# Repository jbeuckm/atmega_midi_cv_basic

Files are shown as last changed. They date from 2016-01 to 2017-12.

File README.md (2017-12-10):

# atmega_midi_cv_basic
Simple gate+pitch+velocity with one 4822

Portamento time is controlled by MIDI CC #5.

When more than one MIDI note is active, the frequency CV is set according to the value of MIDI CC #80 as follows:

CC #80 | Note Priority
--- | ---   
0-31 | Lowest Note
32-63 | Highest Note
64-127 | Highest Velocity (default)

The MIDI channel can be set by sending the following SYSEX message: 
`0x77 0x16 0x01 0x00 0xcc` where cc is the new channel.

Parts placement for Release v0.5:

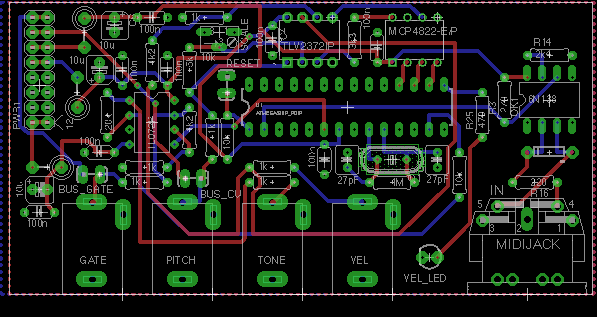
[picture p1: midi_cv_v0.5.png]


For 6N137 instead of 6N138, build with these changes:

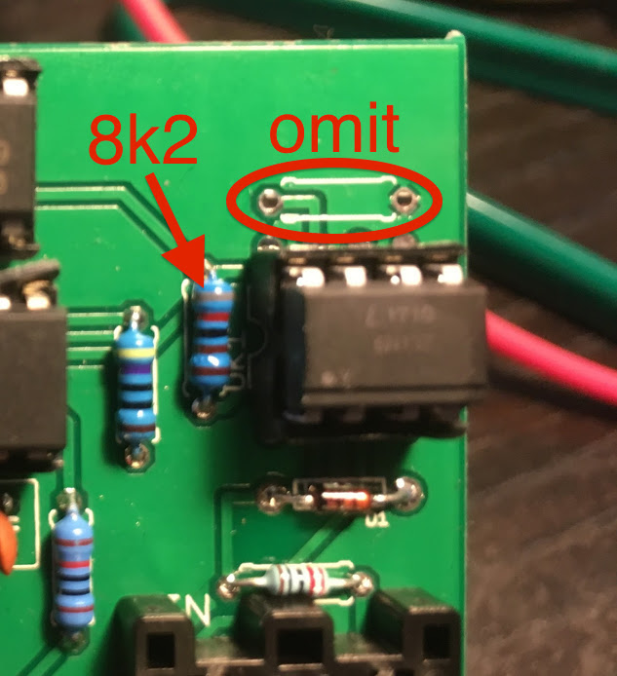
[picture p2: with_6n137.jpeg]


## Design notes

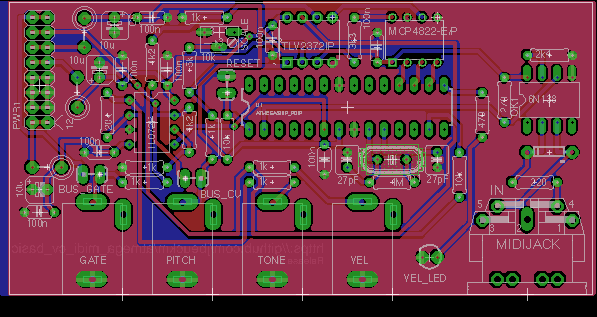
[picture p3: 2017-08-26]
eagle/midi_cv_basic.png

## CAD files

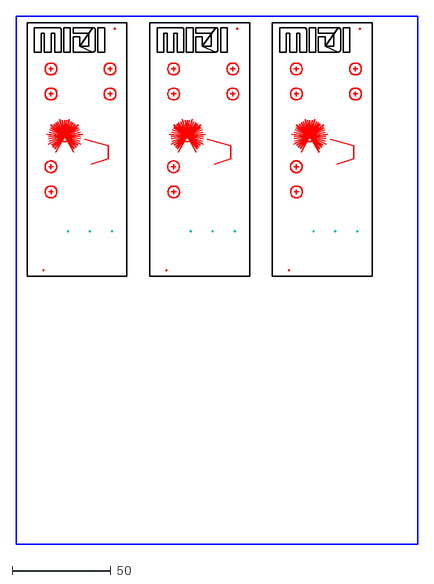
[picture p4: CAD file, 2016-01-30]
panel/basic_midi_cv_panel.dxf
203.2 x 267.2

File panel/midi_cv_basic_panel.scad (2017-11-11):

translate([0,0,2]) rotate([180]) EuroPanel("MIDI", 7);

module EuroPanel(label, hp=8) {
    
  font = ".SF Compact Display:style=Bold";
  labelFontSize = 5.8;

  sideOffset = 5;
  panelWidth = hp*5.08;

  translate([panelWidth,0,0]) scale([-1,1,1]) Support();
  
  
  difference() {
    cube([hp*5.08, 128.5, 2]);
      
    translate([1,118,1])  {
        linear_extrude(height=2, convexity=4) text(label, size=8, font=font);
    }
    translate([7.5,3]) MountingHole();
    translate([panelWidth - 7.5, 128.5 - 3]) MountingHole();

    translate ([sideOffset, 117, 0]) union() {
        translate([0,-87.750,0]) MIDIHole();
        translate([0,-71.39,0]) LEDHole();
        translate([0,-59.97,0]) JackHole();
        translate([0,-44.7,0]) JackHole();
        translate([0,-29.43,0]) JackHole();
        translate([0,-14.17,0]) JackHole();
    }
    translate([18,10,1]) {
      translate([0,90])   {
          linear_extrude(height=2, convexity=4) text("gate", size=labelFontSize, font=font);
      }
      translate([0,75])   {
          linear_extrude(height=2, convexity=4) text("pch", size=labelFontSize, font=font);
      }
      translate([0,60])   {
          linear_extrude(height=2, convexity=4) text("tone", size=labelFontSize, font=font);
      }
      translate([0,45])   {
          linear_extrude(height=2, convexity=4) text("velo", size=labelFontSize, font=font);
      }
  }

  }
/*
    color("green", .3)
        translate([panelWidth - sideOffset, 14.25,2])
            cube([1,100,50]);
            */
}

module KnobHole() { translate([12.5,0,-.5]) cylinder(h=3, d=8, $fn=12); }

module JackHole() { translate([6,0,-.5]) cylinder(h=3, d=6.5, $fn=12); }

module LEDHole() { translate([10,0,-.5]) cylinder(h=3, d=5.3, $fn=12); }

module MIDIHole() { translate([10.5,0,-.5]) cylinder(h=3, d=18.5, $fn=24); }

module Support() {
    translate([0,10,0])
    rotate([-90,0,0])
  linear_extrude(108.5)
    polygon([[0,0], [0,2], [1.5,5], [3,5], [3,0]]);
}


module MountingHole() {
  hull() {
    translate([-2,0,-.5]) cylinder(h=3, r=1.6, $fn=12);
    translate([2,0,-.5]) cylinder(h=3, r=1.6, $fn=12);
  }
}

echo(version=version());

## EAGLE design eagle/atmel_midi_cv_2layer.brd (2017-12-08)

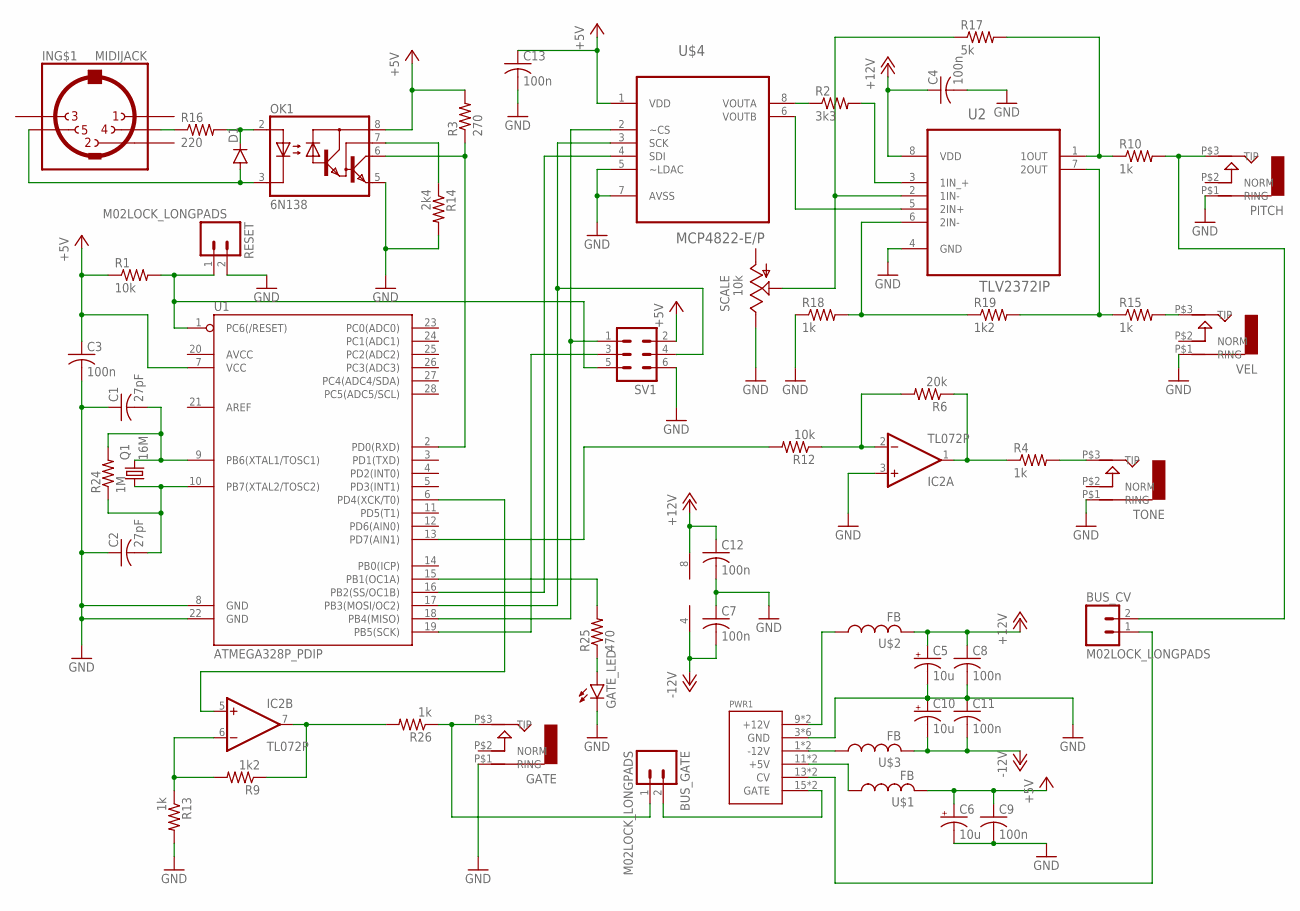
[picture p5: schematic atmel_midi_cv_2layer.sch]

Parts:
BUS_CV: M02LOCK_LONGPADS; 1X02_LOCK_LONGPADS
BUS_GATE: M02LOCK_LONGPADS; 1X02_LOCK_LONGPADS
C1, C2: 27pF; C025-040X050
C3, C4, C7, C8, C9, C11, C12, C13: 100n; C050-024X044
C5, C6, C10: 10u; B45181A
D1: DIODE1N4148; DIODE-1N4148
GATE: AUDIO-JACKITEAD; JACK-90DEG-ITEAD
GATE_LED: LED3MM
IC2: TL072P; DIL08
IN: MIDIJACK; CP-2350
OK1: 6N138; DIL08
PITCH: AUDIO-JACKITEAD; JACK-90DEG-ITEAD
PWR1: POWER; POWER_16
Q1: 16M; HC49/S
R1, R12: 10k; 0207/7
R2: 3k3; 0207/7
R3: 270; 0207/7
R4, R10, R13, R15, R18, R26: 1k; 0207/7
R6: 20k; 0207/7
R9, R19: 1k2; 0207/7
R14: 2k4; 0207/7
R16: 220; 0207/7
R17: 5k; 0207/7
R24: 1M; 0207/7
R25: 470; 0207/7
RESET: M02LOCK_LONGPADS; 1X02_LOCK_LONGPADS
SCALE: 10k; B64W
SV1: MA03-2
TONE: AUDIO-JACKITEAD; JACK-90DEG-ITEAD
U1: ATMEGA328P_PDIP; DIL28-3
U2: TLV2372IP; DIP254P762X508-8
U$1, U$2, U$3: FB
U$4: MCP4822-E/P; DIP254P762X432-8
VEL: AUDIO-JACKITEAD; JACK-90DEG-ITEAD

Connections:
+5V: C3.1, C6.+, C9.1, C13.1, OK1.8 (VCC), R1.1, R3.2, SV1.2, U1.7 (VCC), U$1.P$2 (2), U$4.1 (VDD)
+12V: C4.1, C5.+, C8.1, C12.1, IC2.8 (V+), U2.8 (VDD), U$2.P$2 (2)
-12V: C7.2, C10.-, C11.2, IC2.4 (V-), U$3.P$2 (2)
GND: C1.1, C2.1, C3.2, C4.2, C5.-, C6.-, C7.1, C8.2, C9.2, C10.+, C11.1, C12.2, C13.2, GATE.P$1 (RING), GATE_LED.K (C), IC2.3 (+IN), OK1.5 (GND), PITCH.P$1 (RING), PWR1.3 (GND), PWR1.4 (GND), PWR1.5 (GND), PWR1.6 (GND), PWR1.7 (GND), PWR1.8 (GND), R13.2, R14.2, R18.1, RESET.2, SCALE.E, SV1.6, TONE.P$1 (RING), U1.8 (GND), U1.22 (GND), U2.4 (GND), U$4.5 (~LDAC), U$4.7 (AVSS), VEL.P$1 (RING)
unnamed: BUS_GATE.2, PWR1.15 (GATE), PWR1.16 (GATE)
unnamed: SV1.3, U1.19 (PB5(SCK))
unnamed: C1.2, Q1.2, R24.2, U1.9 (PB6(XTAL1/TOSC1))
unnamed: C2.2, Q1.1, R24.1, U1.10 (PB7(XTAL2/TOSC2))
unnamed: D1.C, OK1.2 (A), R16.2
unnamed: IN.4, R16.1
unnamed: BUS_CV.2, PITCH.P$3 (TIP), R10.2
unnamed: IC2.6 (-IN), R9.2, R13.1
unnamed: PWR1.9 (+12V), PWR1.10 (+12V), U$2.P$1 (1)
unnamed: BUS_CV.1, PWR1.13 (CV), PWR1.14 (CV)
unnamed: IC2.7 (OUT), R9.1, R26.2
unnamed: PWR1.1 (-12V), PWR1.2 (-12V), U$3.P$1 (1)
unnamed: GATE_LED.A, R25.1
unnamed: R15.2, VEL.P$3 (TIP)
unnamed: R25.2, U1.15 (PB1(OC1A))
unnamed: R12.2, U1.13 (PD7(AIN1))
unnamed: IC2.5 (+IN), U1.6 (PD4(XCK/T0))
unnamed: R2.1, U$4.8 (VOUTA)
unnamed: R4.2, TONE.P$3 (TIP)
unnamed: SV1.4, U1.17 (PB3(MOSI/OC2)), U$4.3 (SCK)
unnamed: U1.16 (PB2(SS/OC1B)), U$4.4 (SDI)
unnamed: IC2.2 (-IN), R6.2, R12.1
unnamed: OK1.6 (VO), R3.1, U1.2 (PD0(RXD))
unnamed: BUS_GATE.1, GATE.P$3 (TIP), R26.1
unnamed: OK1.7 (VB), R14.1
unnamed: D1.A, IN.5, OK1.3 (C)
unnamed: PWR1.11 (+5V), PWR1.12 (+5V), U$1.P$1 (1)
unnamed: IC2.1 (OUT), R4.1, R6.1
unnamed: R2.2, U2.3 (1IN_+)
unnamed: R17.1, SCALE.P$1 (S), SCALE.S, U2.2 (1IN-)
unnamed: R18.2, R19.1, U2.6 (2IN-)
unnamed: R15.1, R19.2, U2.7 (2OUT)
unnamed: U2.5 (2IN+), U$4.6 (VOUTB)
unnamed: R10.1, R17.2, U2.1 (1OUT)
unnamed: R1.2, RESET.1, SV1.5, U1.1 (PC6(/RESET))
unnamed: SV1.1, U1.18 (PB4(MISO)), U$4.2 (~CS)

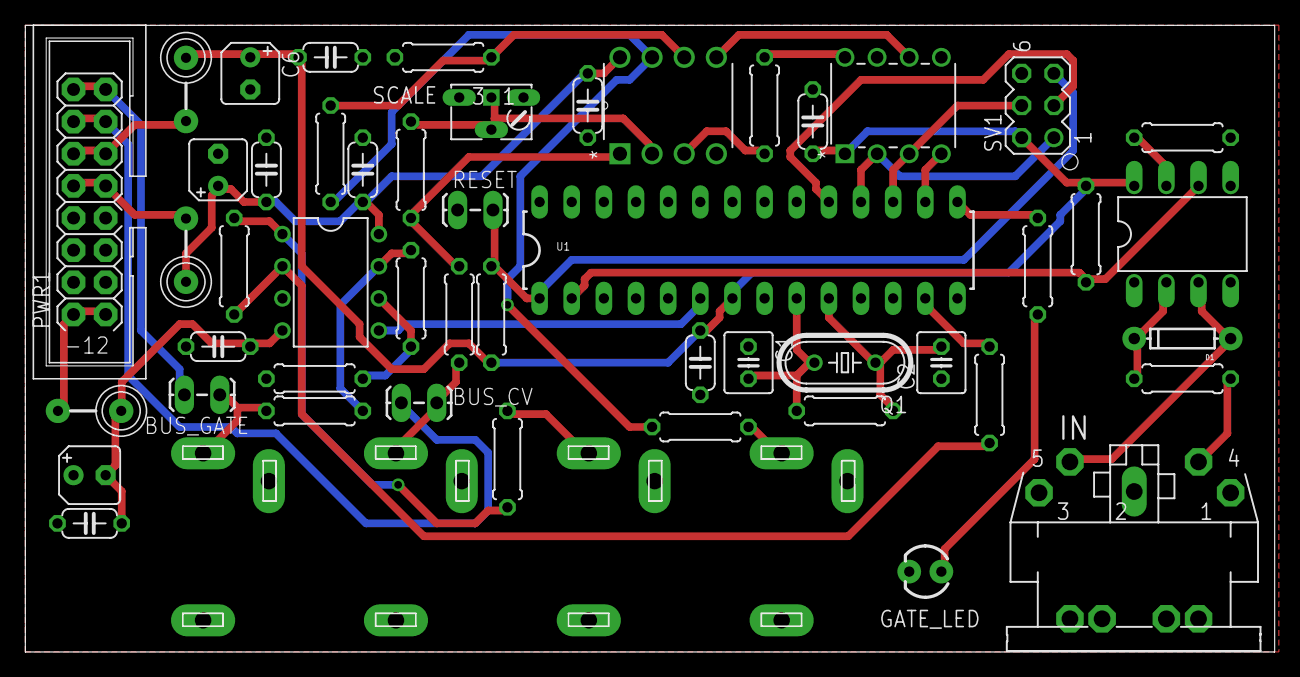
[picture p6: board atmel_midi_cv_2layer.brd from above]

Board: 2 copper layers, 98.7 x 49.5 mm, 53 parts (0 on the bottom side), 40 nets.

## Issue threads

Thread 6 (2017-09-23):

autotune vco

jbeuckm, 2017-09-23:
set up a pin for frequency counter. tune vco to requested scale by trial and error.

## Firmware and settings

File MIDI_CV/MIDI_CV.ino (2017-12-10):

#include <MIDI.h>
#include "AH_MCP4922.h"
#include <EEPROM.h>
#include <avr/pgmspace.h>
#include "notebook.hpp"
#include "digitalWriteFast.h"

NoteBook notebook;

#define LED_PIN 9
#define GATE_PIN 4

#define TONE_PIN 7

#define CC_ALL_NOTES_OFF 123
#define CC_NOTE_PRIORITY 80
#define CC_PORTAMENTO_TIME 5

byte deviceID = 1;

AH_MCP4922 pitchDAC(10,11,12,LOW,LOW);
AH_MCP4922 velocityDAC(10,11,12,HIGH,LOW);

double targetFrequencyCode;
double currentFrequencyCode = 1;
double frequencyCodeSlideRate = 0;
double portamentoTime = 1;
int lastPitch = 0;
volatile uint16_t toneFrequency;
unsigned long noteStartTime;

int pitchbendOffset = 0;

const uint16_t frequency[128] PROGMEM = {8, 9, 9, 10, 10, 11, 12, 12, 13, 14, 15, 15, 16, 17, 18, 19, 21, 22, 23, 24, 26, 28, 29, 31, 33, 35, 37, 39, 41, 44, 46, 49, 52, 55, 58, 62, 65, 69, 73, 78, 82, 87, 92, 98, 104, 110, 117, 123, 131, 139, 147, 156, 165, 175, 185, 196, 208, 220, 233, 247, 262, 277, 294, 311, 330, 349, 370, 392, 415, 440, 466, 494, 523, 554, 587, 622, 659, 698, 740, 784, 831, 880, 932, 988, 1047, 1109, 1175, 1245, 1319, 1397, 1480, 1568, 1661, 1760, 1865, 1976, 2093, 2217, 2349, 2489, 2637, 2794, 2960, 3136, 3322, 3520, 3729, 3951, 4186, 4435, 4699, 4978, 5274, 5588, 5920, 5920, 6645, 7040, 7459, 7902, 8372, 8870, 9397, 9956, 10548, 11175, 11840, 12544};


MIDI_CREATE_DEFAULT_INSTANCE();
byte selectedChannel = 17;

void processNote(char pitch, char velocity) {
  toneFrequency = (unsigned int)pgm_read_word(&frequency[pitch]);

  targetFrequencyCode = (pitch - 12) * 42;
  frequencyCodeSlideRate = (targetFrequencyCode - currentFrequencyCode) / portamentoTime;
  
  velocityDAC.setValue((int)velocity << 5);

  tone(TONE_PIN, toneFrequency + (pitchbendOffset >> 5));
  lastPitch = pitch;
}

Note *result;

void handleNoteOn(byte channel, byte pitch, byte velocity)
{
  noteStartTime = millis();
  result = notebook.noteOn(pitch, velocity);
  processNote(result->pitch, result->velocity);
  digitalWrite(GATE_PIN, HIGH);
  digitalWrite(LED_PIN, HIGH);
}

void updateFrequencyDAC() {

  currentFrequencyCode += frequencyCodeSlideRate * (millis() - noteStartTime);

  if (frequencyCodeSlideRate < 0 && currentFrequencyCode <= targetFrequencyCode) {
    frequencyCodeSlideRate = 0;
    currentFrequencyCode = targetFrequencyCode;
  }
  if (frequencyCodeSlideRate > 0 && currentFrequencyCode >= targetFrequencyCode) {
    frequencyCodeSlideRate = 0;
    currentFrequencyCode = targetFrequencyCode;
  }

  pitchDAC.setValue((int)currentFrequencyCode + pitchbendOffset);  
}

void handleNoteOff(byte channel, byte pitch, byte velocity)
{
  result = notebook.noteOff(pitch);
  
  if (result == 0) {
    digitalWrite(GATE_PIN, LOW);
    digitalWrite(LED_PIN, LOW);
  } else {
    processNote(result->pitch, result->velocity);
  }
}


void handleControlChange(byte channel, byte number, byte value)
{
  switch (number) {

    case CC_PORTAMENTO_TIME:
      portamentoTime = 1.0 + 4.0 * pow(value, 3.5);
      break;
        
    case CC_NOTE_PRIORITY:
      if (value >= 64) {
        notebook.setMode(velocity);
      } else if (value >= 32) {
        notebook.setMode(highest);
      } else {
        notebook.setMode(lowest);
      }
      break;
        
    case CC_ALL_NOTES_OFF:
      notebook.allNotesOff();
      handlePitchBend(selectedChannel, 0);
      digitalWrite(GATE_PIN, LOW);
      digitalWrite(LED_PIN, LOW);
      break;
  }
}


void handlePitchBend(byte channel, int bend)
{
  pitchbendOffset = bend >> 4;

  tone(TONE_PIN, toneFrequency + (pitchbendOffset >> 5));
}


void setMidiChannel(byte newChannel) {
  newChannel = newChannel % 17;
  if (newChannel == 0) {
    newChannel = 1;
  }
  EEPROM.update(0, newChannel);
  MIDI.begin(newChannel);
  playScale(newChannel);
  
}


void handleSystemExclusive(byte message[], unsigned size) {
  
  if (message[1] != 0x77) return;      // manufacturer ID
  if (message[2] != 0x16) return;      // model ID
  if (message[3] != deviceID) return;  // device ID 
  
  switch (message[4]) {
    
    case 0x00:
      setMidiChannel(message[5]);
      break;
    
    default:
      break;
  }

}


// -----------------------------------------------------------------------------

void setup()
{
    selectedChannel = EEPROM.read(0);
    if (selectedChannel > 16) {
      selectedChannel = 1;
      EEPROM.update(0, selectedChannel);
    }

    pinMode(LED_PIN, OUTPUT);
    digitalWrite(LED_PIN, LOW);
    pinMode(GATE_PIN, OUTPUT);
    digitalWrite(GATE_PIN, LOW);

    delay(500);

    playScale(selectedChannel);

    // calibrate 8V
    // calibrate full velocity
    handleNoteOn(selectedChannel, 108, 127);
    handleNoteOff(selectedChannel, 108, 127);

    MIDI.setHandleNoteOn(handleNoteOn);
    MIDI.setHandleNoteOff(handleNoteOff);
    MIDI.setHandlePitchBend(handlePitchBend);
    MIDI.setHandleControlChange(handleControlChange);
    MIDI.setHandleSystemExclusive(handleSystemExclusive);

    setMidiChannel(selectedChannel);
}

void playScale(int channel) {

  int note = 60;

  for (int i=0; i<channel; i++) {

      handleNoteOn(channel, note, 100);
      delay(50);
      handleNoteOff(channel, note, 100);
      delay(50);
      note++;
  }

}

void loop()
{
    MIDI.read();
    updateFrequencyDAC();
}

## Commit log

2016-01-05 velocity gate led
    [atmel_midi_cv_basic.sch]
2016-01-05 board near complete
    [atmel_midi_cv_basic.brd, atmel_midi_cv_basic.sch]
2016-01-06 sloppy routed
    [atmel_midi_cv_basic.brd]
2016-01-06 will try cut
    [atmel_midi_cv_basic.sch]
2016-01-06 led fixed
    [atmel_midi_cv_basic.brd, atmel_midi_cv_basic.sch]
2016-01-08 playing scale to indicate midi channel by number of notes
    [atmel_midi_cv_basic.brd, atmel_midi_cv_basic.sch]
2016-01-08 no neg supply
    [atmel_midi_cv_basic.brd, atmel_midi_cv_basic.sch]
2016-01-10 swapping atmega pin 16 and 17 for layout convenience
    [atmel_midi_cv_basic.brd, atmel_midi_cv_basic.sch]
2016-01-12 possible route
    [atmel_midi_cv_basic.brd, atmel_midi_cv_basic.sch]
2016-01-12 new gcode
    [atmel_midi_cv_basic.brd]
2016-01-12 layout tweaked
    [atmel_midi_cv_basic.brd]
2016-01-14 fixed led output to pwm pin and schematic consistent
    [atmel_midi_cv_basic.brd, atmel_midi_cv_basic.sch]
2016-08-20 cleaned up some routes
    [atmel_midi_cv_basic.brd, atmel_midi_cv_basic.sch]
2016-08-23 corrected wrong gate pin and tl072 back to bipolar to prevent locking
    [atmel_midi_cv_basic.brd, atmel_midi_cv_basic.sch]
2017-08-25 rail2rail pitch amp, tone output, improved decoupling, board mount midi jack, more isolation
    [atmel_midi_cv_2layer.sch, atmel_midi_cv_basic.brd]
2017-08-25 merged many 9 to GND
    [atmel_midi_cv_2layer.brd, atmel_midi_cv_2layer.sch]
2017-08-26 started software update
    [atmel_midi_cv_2layer.brd, atmel_midi_cv_2layer.sch]
2017-08-26 removed old files
    [atmel_midi_cv_basic.brd, atmel_midi_cv_basic.sch]
2017-08-26 added url and release to silkscreen
    [atmel_midi_cv_2layer.brd, atmel_midi_cv_2layer.sch]
2017-08-26 removed part number clutter
    [atmel_midi_cv_2layer.brd]
2017-08-26 layout tweaks
    [atmel_midi_cv_2layer.brd]
2017-08-27 sent the files
    [atmel_midi_cv_2layer.brd]
2017-09-20 ICSP added and rerouted
    [atmel_midi_cv_2layer.brd, atmel_midi_cv_2layer.sch]
2017-09-20 updated power with shroud
    [atmel_midi_cv_2layer.brd, atmel_midi_cv_2layer.sch]
2017-09-23 setting pitch on 1khz interrupt and just sending target freq code
2017-09-23 removed pitch dac set from setup calibration value
2017-10-14 turned off 1khz timer and implemented pitchbend for tone output
2017-10-15 gate pin added and working same as LED pin
2017-10-18 preparing to update dac and tone frequency at audio rate to avoid timer interrupt conflicts
    [MIDI_CV.ino]
2017-10-20 processing portamento with millis() in the loop()
2017-10-21 fixed type and tuned portamento time
    [MIDI_CV.ino]
2017-11-04 updated panel
    [midi_cv_basic_panel.scad]
2017-11-06 adjusted midi label location
    [midi_cv_basic_panel.scad]
2017-11-11 minor tweaks
    [midi_cv_basic_panel.scad]
2017-12-08 route better clearance for midi resistor and scale pot
    [atmel_midi_cv_2layer.brd]
2017-12-08 label tweaks and power filter moved
    [atmel_midi_cv_2layer.brd, atmel_midi_cv_2layer.sch]

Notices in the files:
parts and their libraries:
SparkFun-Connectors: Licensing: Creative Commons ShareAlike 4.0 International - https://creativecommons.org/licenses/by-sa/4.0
